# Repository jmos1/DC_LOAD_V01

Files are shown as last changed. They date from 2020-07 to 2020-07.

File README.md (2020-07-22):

# DC_LOAD_V01
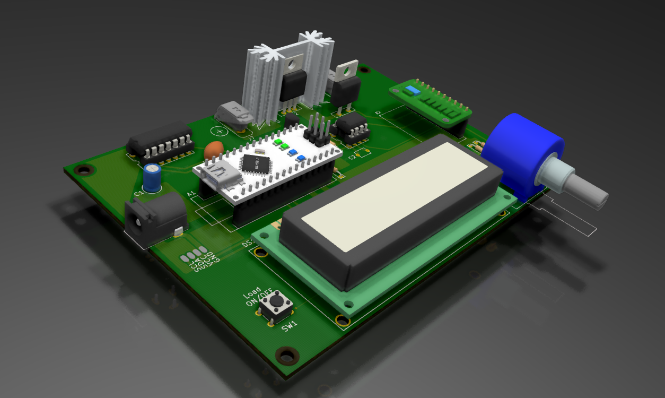
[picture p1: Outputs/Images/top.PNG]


### Summary: ###
  This is a functional PCB prototype of a 1-amp constant current DC load
  which will precede a much stronger 5-amp load in the future. This
  tool can be used for testing batteries and other power sources <= 1 amp.
  
  The BOM, schematic PDF, and gerber files are all accessible in the _'Outputs/'_ folder. 
  Other project files are not included because they add clutter and can be generated from the project itself in KiCad.
  Thanks.
  
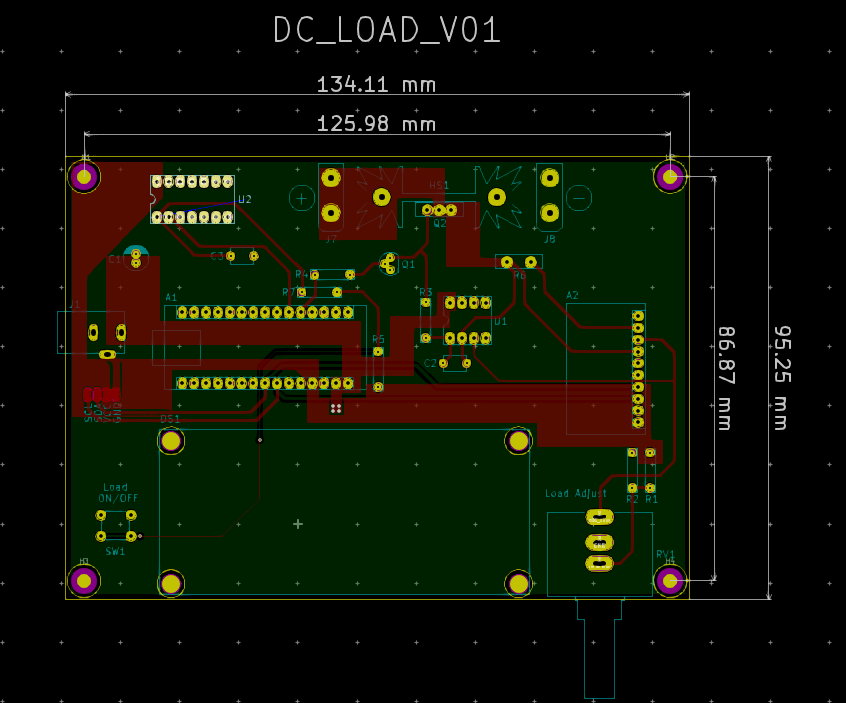
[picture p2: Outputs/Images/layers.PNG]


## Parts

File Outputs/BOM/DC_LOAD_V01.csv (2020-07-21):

Comment | MPN | Manufacturer | Part Number | Supplier | Quantity
Arduino Nano | X | X | X | https://www.amazon.com/ELEGOO-Arduino-ATmega328P-Without-Compatible/dp/B0713XK923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 | 1
ADS1115 Breakout Board | X | X | X | https://www.amazon.com/gp/product/B07TGB6KF8/ref=ppx_yo_dt_b_asin_title_o03_s00?ie=UTF8&psc=1 | 1
100uF, 25V | UVY1E101MDD1TD | Nichicon | 493-12902-1-ND | DigiKey | 1
47n, 50V | NF | NF | NF | NF | 1
Generic 2u2F THT Ceramic Capacitor | X | X | X | https://www.amazon.com/gp/product/B071ZFKJK7/ref=ppx_yo_dt_b_asin_title_o06_s00?ie=UTF8&psc=1 | 1
16x2 I2C LCD | X | X | X | https://www.amazon.com/JANSANE-Arduino-Display-Interface-Raspberry/dp/B07D83DY17?s=electronics | 1
TO-220 Heatsink | X | X | X | https://www.amazon.com/Electronics-Salon-Heatsink-Small-Aluminum-Heat-Sink/dp/B074MVHPRL | 1
PJ-102AH | PJ-102AH | CUI Devices | CP-102AH-ND | DigiKey | 1
2x4_DIP_SOCKET | 110-87-308-41-001101 | Preci-Dip | 1212-1003-ND | DigiKey | 1
2x7_DIP_SOCKET | AR 14 HZL-TT | Assmann WSW Components | AE10012-ND | DigiKey | 1
1x15_HDR_FEMALE | PPTC151LFBN-RC | Sullins Connector Solutions | S7013-ND | DigiKey | 2
1x10_HDR_FEMALE | PPTC101LFBN-RC | Sullins Connector Solutions | S7008-ND | DigiKey | 1
SR99S01VBNN04G7 | SR99S01VBNN04G7 | METZ CONNECT USA Inc. | 1849-1159-1-ND | DigiKey | 2
2N2222A NPN Transistor | X | X | X | https://www.amazon.com/Hilitchi-675-Piece-2N2222-S9018-Transistors-Assortment/dp/B06Y49GB3F | 1
IRFZ44NPBF | IRFZ44NPBF | Infineon Technologies | IRFZ44NPBF-ND | DigiKey | 1
Generic 1K2R 1/4W THT Resistor | X | X | X | https://www.amazon.com/SIQUK-Resistors-Resistor-Assortment-Experiments/dp/B07PTNN78Z | 1
Generic 1KR 1/4W THT Resistor | X | X | X | https://www.amazon.com/SIQUK-Resistors-Resistor-Assortment-Experiments/dp/B07PTNN78Z | 3
0R500 | MP930-0.50-1% | Caddock Electronics Inc. | MP930-0.50F-ND | DigiKey | 1
Generic 10KR 1/4W THT Resistor | X | X | X | https://www.amazon.com/SIQUK-Resistors-Resistor-Assortment-Experiments/dp/B07PTNN78Z | 2
10-Turn 10KR Potentiometer | 3590S-2-103L | Bounrs Inc. | 3590S-2-103L-ND | DigiKey | 1
1825910-6 | 1825910-6 | TE Connectivity ALCOSWITCH Switches | 450-1650-ND | DigiKey | 1
LM358P | LM358P | Texas Instruments | 296-1395-5-ND | DigiKey | 1
SN74HC14N | SN74HC14N | Texas Instruments | 296-1577-5-ND | DigiKey | 1

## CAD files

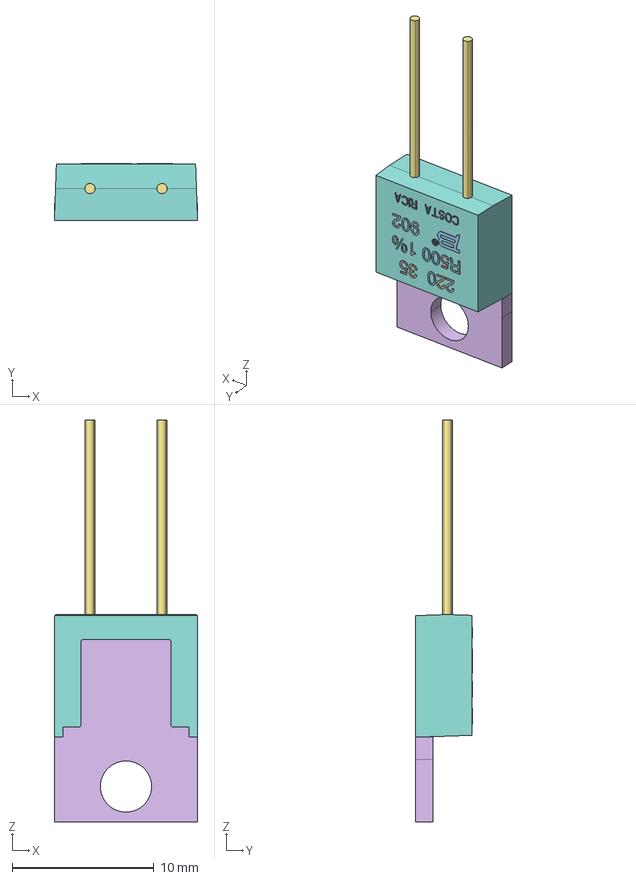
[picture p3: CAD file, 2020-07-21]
3D Models/PWR220T-35-R(SENSE RESISTOR).stp
10.1 x 4.03 x 28.3 mm
B-13078-00-SNAPSTRATE
B-13078-01-TERM
B-13078-08-BOT-SOLDER
B-13078-03-TOP-RESIST
B-13078-04-GLAZE
34544-08202-BACK-PLATE
PWR220-PIN x 2
B-13096-HSG
B-13097-MARKING

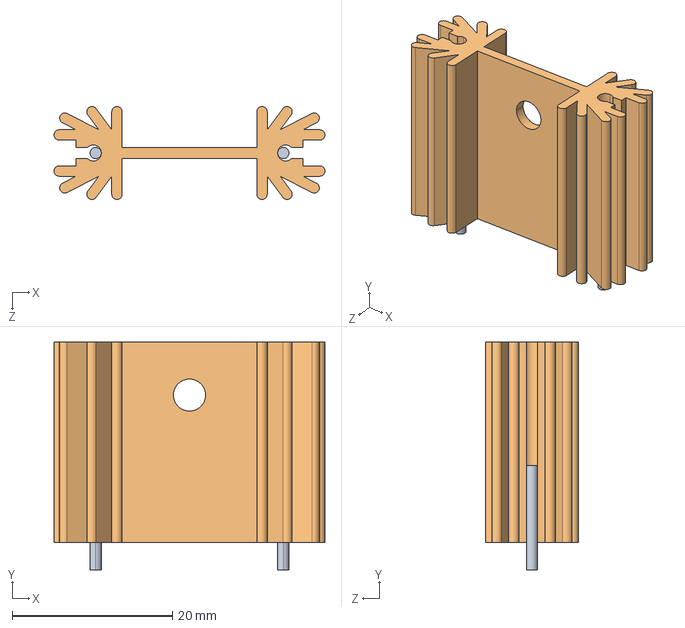
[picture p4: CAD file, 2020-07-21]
3D Models/HeatSink TO220.step
33.8 x 28.4 x 11.6 mm

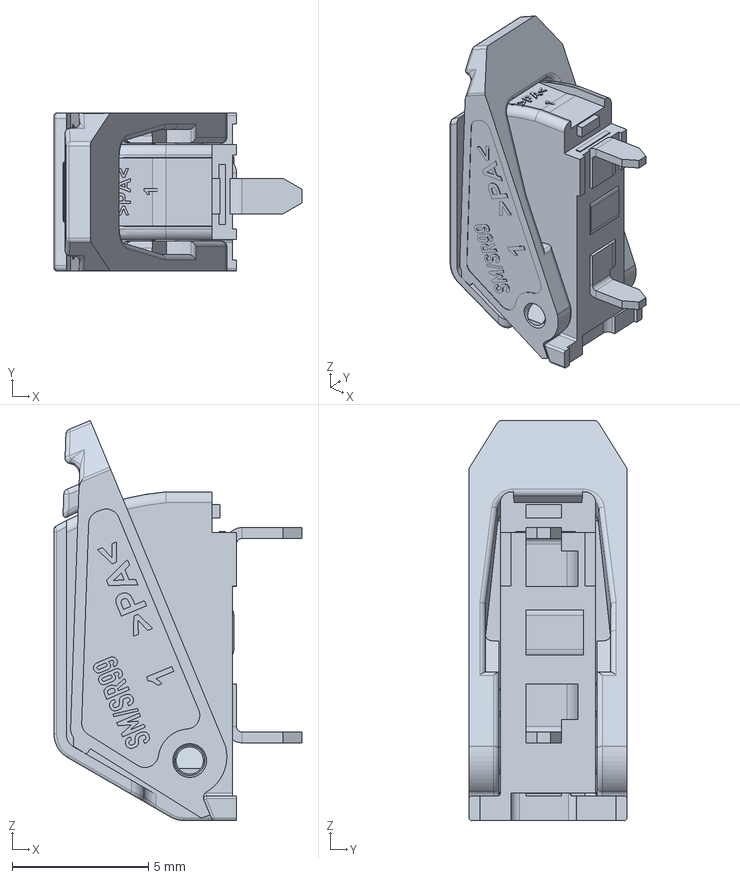
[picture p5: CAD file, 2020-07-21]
3D Models/SR99.stp
9.10 x 5.80 x 14.7 mm

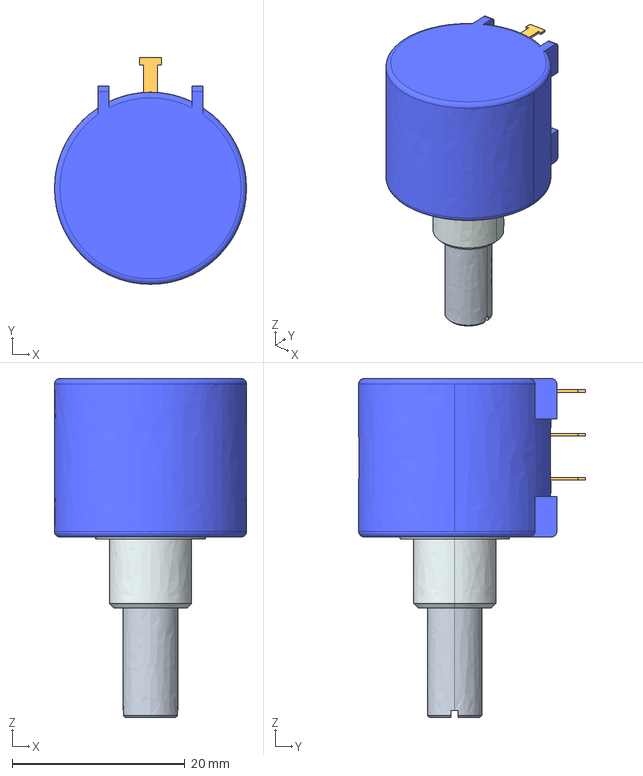
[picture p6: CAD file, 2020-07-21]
3D Models/10-turn-pot.stp
22.2 x 26.2 x 39.2 mm

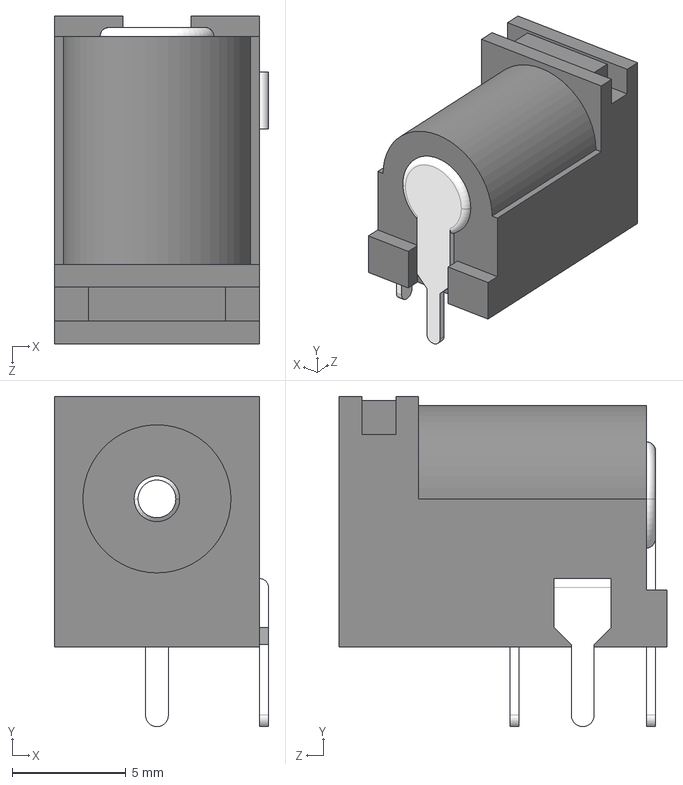
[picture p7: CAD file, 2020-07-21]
3D Models/PJ-102AH.STEP
9.40 x 14.5 x 14.4 mm

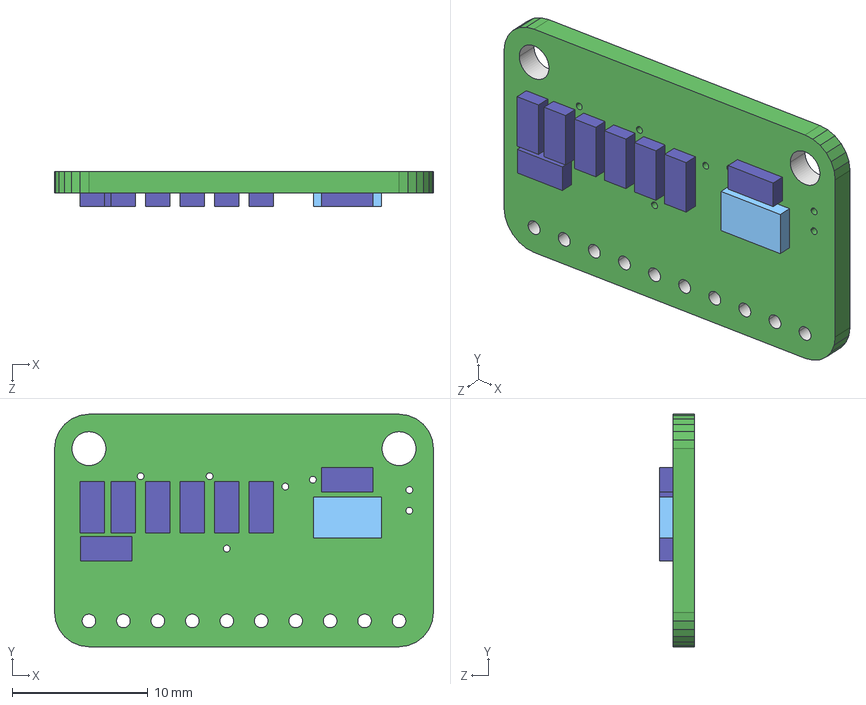
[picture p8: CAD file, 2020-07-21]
3D Models/ads1115_16bit_i2c_adc.step
27.9 x 17.1 x 2.60 mm

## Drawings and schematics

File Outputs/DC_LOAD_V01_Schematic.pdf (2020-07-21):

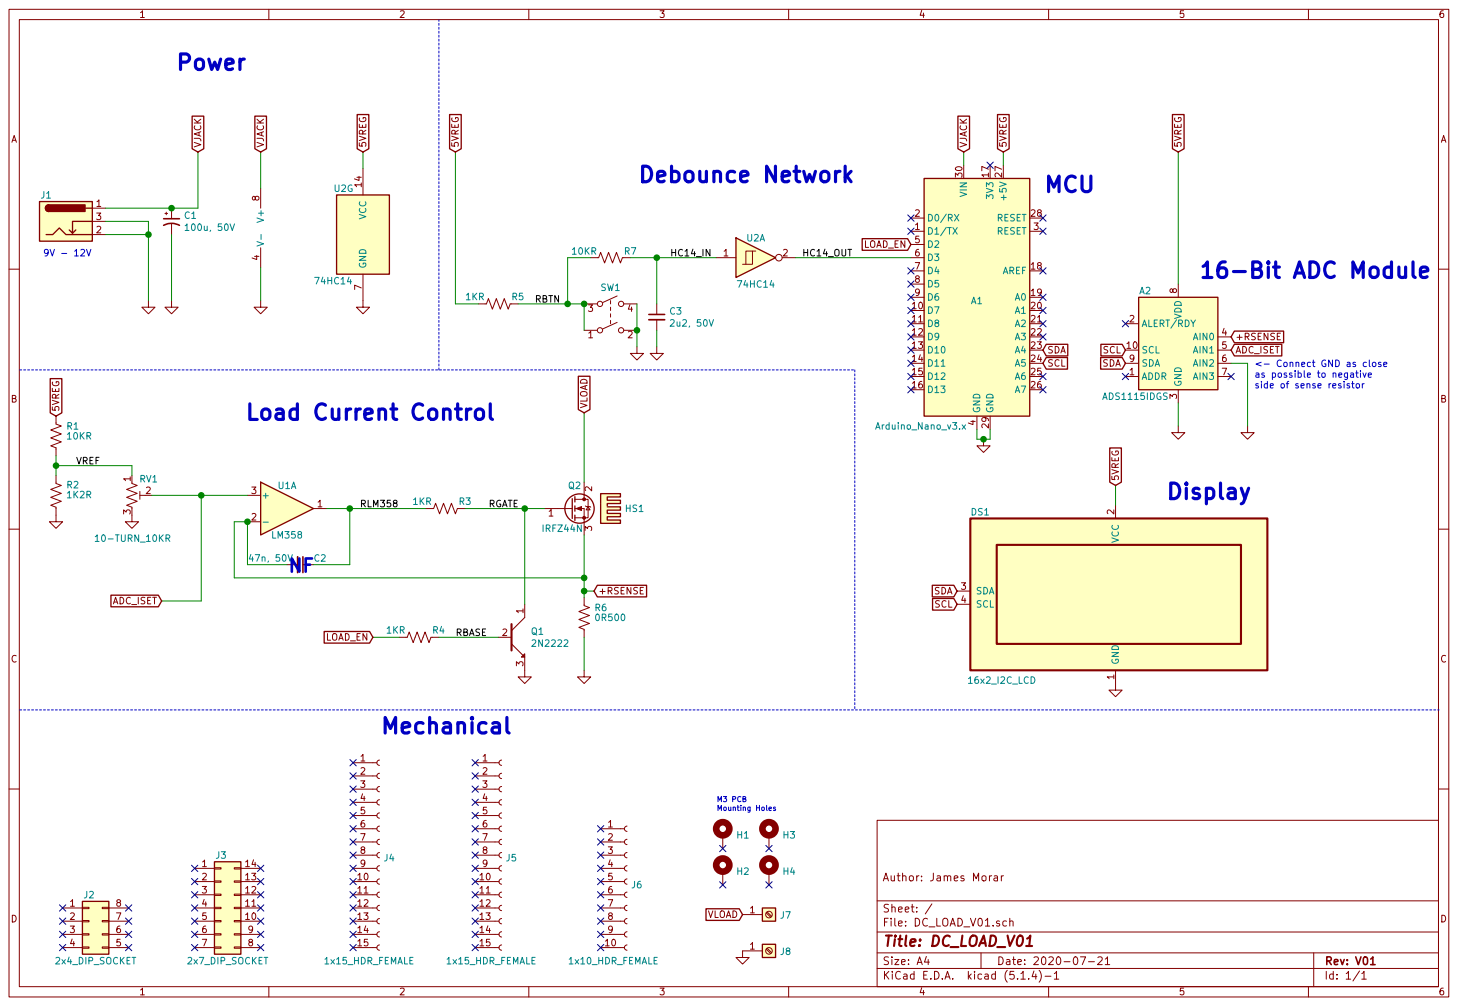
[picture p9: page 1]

side of sense resistor MCU

<- Connect GND as close
as possible to negative

File: DC_LOAD_V01.sch Sheet: / Author: James Morar 1

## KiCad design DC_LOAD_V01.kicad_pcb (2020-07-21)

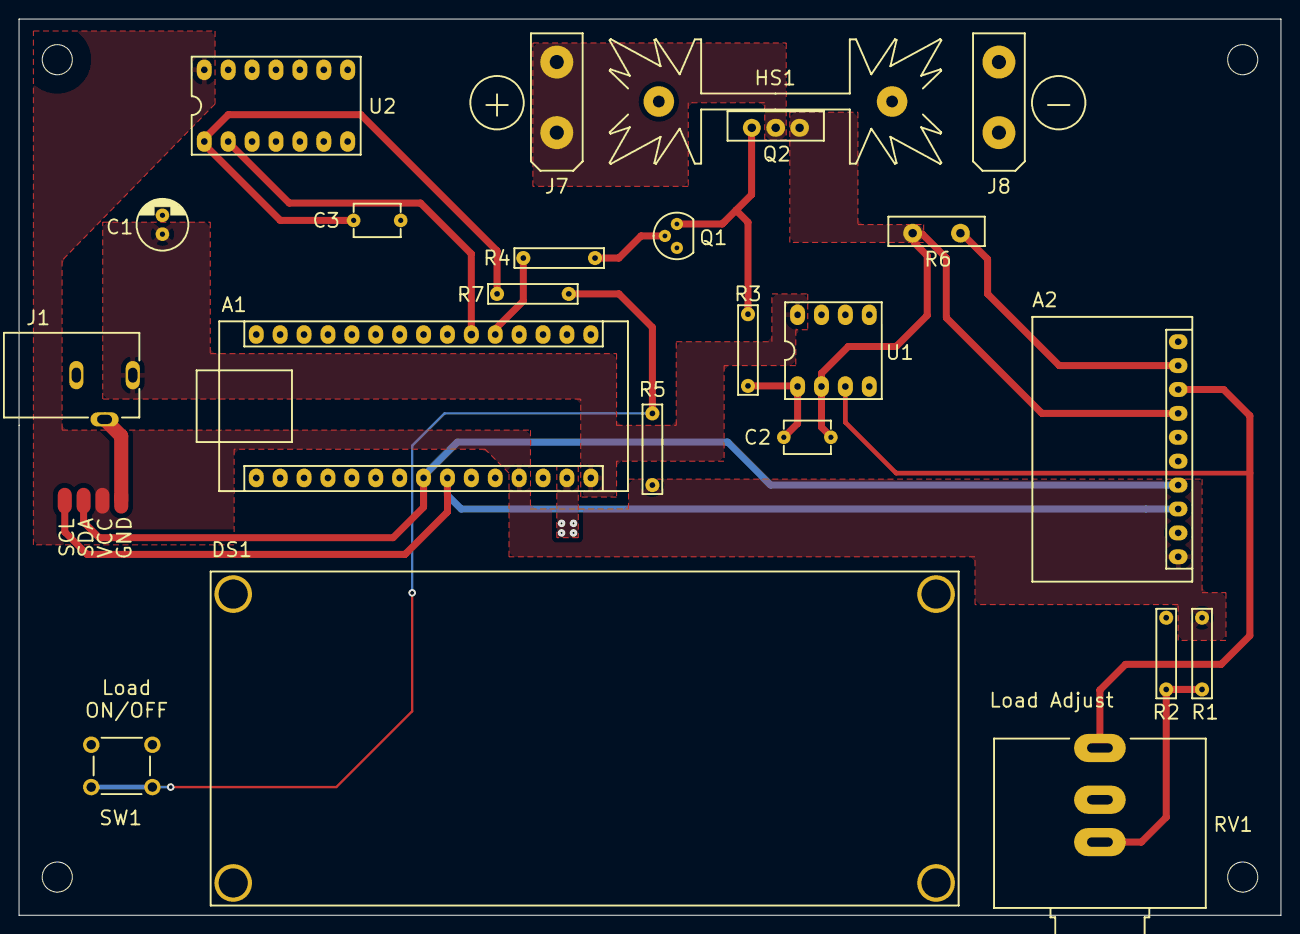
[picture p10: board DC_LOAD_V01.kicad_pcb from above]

Board: 2 copper layers, 134.1 x 95.2 mm, 27 parts (0 on the bottom side), 16 nets.

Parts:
A1: Arduino_Nano_v3.x; Arduino_Nano
A2: ADS1115IDGS; ADS1115
C1: 100u; CP_Radial_D5.0mm_P2.00mm
C2: 47n; C_Axial_P5.0mm
C3: 2u2; C_Axial_P5.0mm
DS1: 16x2_I2C_LCD
H1, H2, H3, H4: MountingHole_Pad; MountingHole_3.2mm_M3
HS1: Heatsink; Heatsink_Fischer_SK104-STC-STIC_35x13mm_2xDrill2.5mm
J1: Barrel_Jack_Switch; CUI_PJ-102AH
J7, J8: Screw_Terminal_01x01; SCREW_TERM
Q1: 2N2222; TO-92
Q2: IRFZ44N; TO-220-3_Vertical
R1, R7: 10KR; R_Axial_DIN0204_L3.6mm_D1.6mm_P7.62mm_Horizontal
R2, R3, R4, R5: 1KR; R_Axial_DIN0204_L3.6mm_D1.6mm_P7.62mm_Horizontal
R6: 0R500; TO-220-2_Vertical
RV1: 10-TURN_10KR; 10KPOT_10TURN
SW1: SW_DPST; SW_1825910-6-4
U1: LM358; DIP-8_W7.62mm_LongPads
U2: 74HC14; DIP-14_W7.62mm_Socket_LongPads

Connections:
5VREG: A1.27, A2.8, DS1.2, R1.1, R5.1, U2.14
+RSENSE: A2.4, C2.2, Q2.3, R6.1, U1.2
/HC14_IN: C3.1, R7.1, U2.1
/HC14_OUT: A1.6, U2.2
/RGATE: Q1.1, Q2.1, R3.2
/RLM358: C2.1, R3.1, U1.1
ADC_ISET: A2.5, RV1.2, U1.3
GND: A1.4, A1.29, A2.3, A2.6, C1.2, C3.2, DS1.1, J1.2, J1.3, J8.1, Q1.3, R2.1, R6.2, RV1.3, SW1.2, SW1.4, U1.4, U2.7
LOAD_EN: A1.5, R4.1
unnamed: Q1.2, R4.2
unnamed: R1.2, R2.2, RV1.1
unnamed: R5.2, R7.2, SW1.1, SW1.3
SCL: A1.24, A2.10, DS1.4
SDA: A1.23, A2.9, DS1.3
VJACK: A1.30, C1.1, J1.1, U1.8
VLOAD: J7.1, Q2.2

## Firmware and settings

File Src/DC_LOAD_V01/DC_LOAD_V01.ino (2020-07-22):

/* Author: James Morar
 * Date: 07/22/2020
 * 
 * Summary: This is the software for driving the DC_LOAD_V01 board on github: https://github.com/jmos1/DC_LOAD_V01         
 */
#include <Wire.h>
#include <LiquidCrystal_I2C.h>
#include <Adafruit_ADS1015.h>

#define MOSFET_OFF            0
#define MOSFET_ON             1
#define SCREEN_LOAD_EN        1
#define SCREEN_LOAD_DI        0
#define PIN_LOAD_BTN          3
#define PIN_TRANSISTOR_BASE   2

int16_t adc_reading_shunt, adc_reading_pot;
uint8_t mosfet_state = MOSFET_OFF, screen_state = SCREEN_LOAD_DI;
int sum_shunt = 0, sum_pot = 0;
float nominal_current = 0, actual_current = 0;
long unsigned screen_clear_time = 0, screen_set_time = 0;

Adafruit_ADS1115 ads;               //Initialize ADC
LiquidCrystal_I2C lcd(0x27, 16, 2); //Iniitialize LCD

void setup(void) 
{
  lcd.init();  
  lcd.noCursor();                  
  lcd.backlight();
  lcd.clear();
  lcd.home();
  lcd.print("Set: 0.00 Amps  ");
  lcd.setCursor(0,1);
  lcd.print("Load: 0.00 Amps   ");

  pinMode(PIN_TRANSISTOR_BASE, OUTPUT);       //BJT collector is connected to MOSFET gate in order to sink current and shut it off/on
  digitalWrite(PIN_TRANSISTOR_BASE, HIGH);    //Open collector configuration so when BJT is ON, primary MOSFET is OFF.
  pinMode(PIN_LOAD_BTN, INPUT);               //Button that will control the turning off and on of the transistors.

  attachInterrupt(digitalPinToInterrupt(PIN_LOAD_BTN), load_button_isr, RISING); 
 
  // The ADC input range (or gain) can be changed via the following
  // functions, but be careful never to exceed VDD +0.3V max, or to
  // exceed the upper and lower limits if you adjust the input range!
  // Setting these values incorrectly may destroy your ADC!
  //                                                                ADS1015  ADS1115
  //                                                                -------  -------
  // ads.setGain(GAIN_TWOTHIRDS);  // 2/3x gain +/- 6.144V  1 bit = 3mV      0.1875mV (default)
  // ads.setGain(GAIN_ONE);        // 1x gain   +/- 4.096V  1 bit = 2mV      0.125mV
  // ads.setGain(GAIN_TWO);        // 2x gain   +/- 2.048V  1 bit = 1mV      0.0625mV
  // ads.setGain(GAIN_FOUR);       // 4x gain   +/- 1.024V  1 bit = 0.5mV    0.03125mV
  // ads.setGain(GAIN_EIGHT);      // 8x gain   +/- 0.512V  1 bit = 0.25mV   0.015625mV
  // ads.setGain(GAIN_SIXTEEN);    // 16x gain  +/- 0.256V  1 bit = 0.125mV  0.0078125mV
  
  ads.begin();                                                                                                                                                                                                                                                                                                                                                                                                                                                                                                                                                                                                                                                                                                                                                                                                                                                                                                                                                                                                                                                                                                                                                                                                                                                                                                                                                                                                                                                                                                                                                                                                                                                                                                                                                                                                                                                                                                                                                                                                                                                                                                                                                                                                                                                                                                                                                                                                                                                                                                                                                                                                                                                                                                                                                                                                                                                                                                                                                                                                                                                                                                                                                                                                                                                                                                                                                                                                                                                                                                                                                                                                                                                                                                                                                                                                                                                                                                                                                                                                                                                                                                                                                                                                                                                                                                                                                                                                                                                                                                                                                                                                                                                                                                                                                                                                                                                                                                                                                                                                                                                                                                                                                                                                                                                                                                                                                                                                                                                                                                                                                                                                                                                                                                                                                                                                                                                                                                                                                                                                                                                                                                                                                                                                                                                                                                                                                                                                                                                                                                                                                                                                                                                                                                                                                                                                                                                                                                                                                                                                                                                                                                                                                                                                                                                                                                                                                                                                                                                                                                                                                                                                                                                                                                                                                                                                                                                                                                                                                                                                                                                                                                                                                                                                                                                                                                                                                                                                                                                                                                                                                                                                                                                                                                                                                                                                                                                                                                                                                                                                                                                                                                                                                                                                                                                                                                                                                                                                                                                                                                                                                                                                                                                                                                                                                                                                                                                                                                                                                                                                                                                                                                                                                                                                                                                                                                                                                                                                                                                                                                                                                                                                                                                                                                                                             
  
}

void loop(void) 
{
  //---Read the desired current from potentiometer---//
  for (uint8_t j = 0; j < 5; j++) 
  {
    adc_reading_pot = ads.readADC_SingleEnded(1);
    sum_pot += adc_reading_pot;
  }
  nominal_current = (float(sum_pot/5) * .0001875) / .5;

  //---Read the actual current flowing through current shunt---//
  for (uint8_t i = 0; i < 5; i++) 
  {
    adc_reading_shunt = ads.readADC_SingleEnded(0);
    sum_shunt += adc_reading_shunt;
  }
  actual_current = (float(sum_shunt/5) * .0001875) / .5;
 
  if(mosfet_state == MOSFET_OFF) 
  {
    digitalWrite(PIN_TRANSISTOR_BASE, HIGH);
    
    if(millis() - screen_set_time >= 500 && screen_state == SCREEN_LOAD_EN) //clear screen after it has displayed for 500 ms
    { 
      lcd.setCursor(0,1);
      lcd.print("                ");
      screen_set_time = millis();
      screen_clear_time = millis();
      screen_state = SCREEN_LOAD_DI;
    }

    if(millis() - screen_clear_time >= 250 && screen_state == SCREEN_LOAD_DI) //Set screen after it has been cleared for 250 ms
    { 
      lcd.setCursor(0,1);
      if (actual_current > 0 )
      {
        lcd.print("Load: "); lcd.print(actual_current); lcd.print(" Amps   ");
      }
      else 
      {
        lcd.print("Load: 0.00 Amps  ");
      }
      screen_clear_time = millis();
      screen_set_time = millis();
      screen_state = SCREEN_LOAD_EN;
    }

    lcd.home();
    if (nominal_current > 0 )
    {
      lcd.print("Set: "); lcd.print(nominal_current); lcd.print(" Amps   ");
    }
    else 
    {
      lcd.print("Set: 0.00 Amps  ");
    }
    
  }
  else 
  {
    digitalWrite(PIN_TRANSISTOR_BASE, LOW);

    lcd.home();
    if (nominal_current > 0 )
    {
      lcd.print("Set: "); lcd.print(nominal_current); lcd.print(" Amps   ");
    }
    else 
    {
      lcd.print("Set: 0.00 Amps  ");
    }

    lcd.setCursor(0,1);
    if (actual_current > 0 )
    {
      lcd.print("Load: "); lcd.print(actual_current); lcd.print(" Amps   ");
    }
    else 
    {
      lcd.print("Load: 0.00 Amps  ");
    }
    
  }
  sum_pot = 0;
  sum_shunt = 0;
}

//---ISR to toggle the MOSFET on and off---//
void load_button_isr()
{
  mosfet_state = !mosfet_state;
}
